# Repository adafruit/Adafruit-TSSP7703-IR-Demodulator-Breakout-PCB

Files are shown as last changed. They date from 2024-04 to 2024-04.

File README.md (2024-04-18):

## Adafruit TSSP77038 38KHz Infrared IR Demodulator Breakout - STEMMA JST PH 2mm PCB

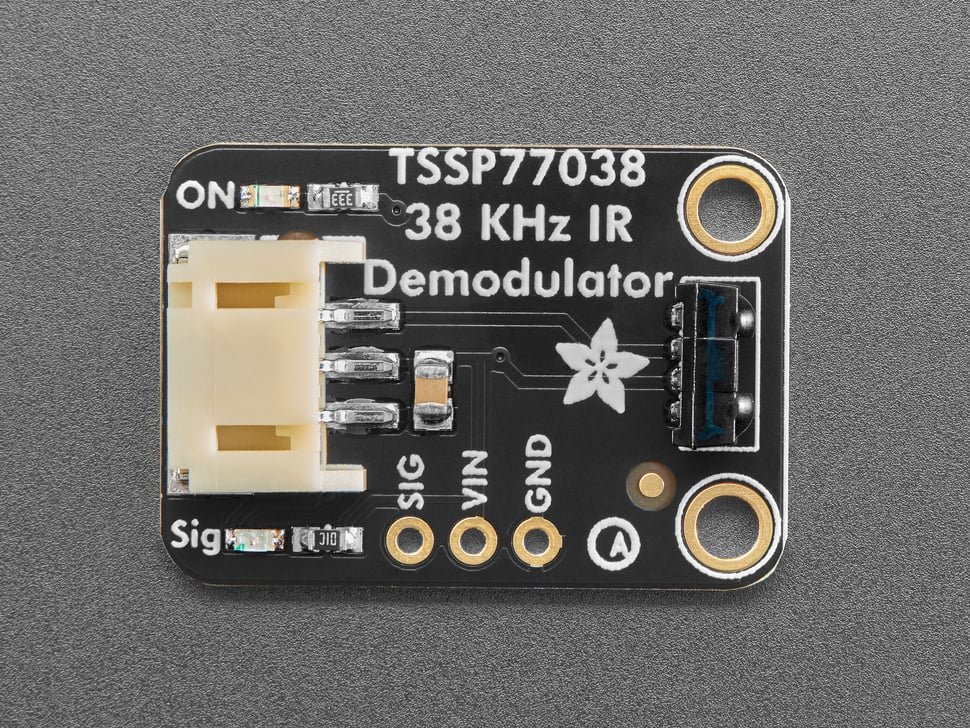
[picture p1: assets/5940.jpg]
<a href="http://www.adafruit.com/products/5940"><br/>
Click here to purchase one from the Adafruit shop</a>

PCB files for the Adafruit TSSP77038 38KHz Infrared IR Demodulator Breakout - STEMMA JST PH 2mm. 

Format is EagleCAD schematic and board layout
* https://www.adafruit.com/product/5940

### Description

While designing our IR decoding breakout we noticed the TSSP series of chips from Vishay, these are simpler than more 'remote control' receivers in that they don't do any filtering on the codes received: you really just get the demodulated-from-38KHz-signal output.

According to Vishay, they're designed for "Reflective Sensing, Light Barriers, and Fast Proximity Applications". These sensors could be interesting for use when you want a less-'intelligent' IR decoder, or for proximity projects where you don't want to go all-out for a VCNL I2C sensor. These are good for creating break-beams where the IR light is modulated rather than just solid on, because you won't be affected by other IR signals or ambient light changes.

This board will work nicely for a variety of IR detecting projects, and with mounting holes and a cable, a lot easier to mount in enclosures and on devices. Using a 2mm pitch STEMMA JST PH cable with headers or alligator clips on the end, you can easily wire this board without any soldering.

Note that this board is specifically for proximity sensing or break-beam projects, while it can receive 38KHz IR remote control signals - there isn't a filter system so you'll get a lot of spurious signals.

Each STEMMA board is a fully assembled and tested PCB but no cable. No soldering is required to use it, but you will need to pick up a 2mm pitch, 3-pin STEMMA JST PH cable. Alternatively, if you do want to solder, there's a 0.1" spaced header for power/ground/signal.

### License

Adafruit invests time and resources providing this open source design, please support Adafruit and open-source hardware by purchasing products from [Adafruit](https://www.adafruit.com)!

Designed by Limor Fried/Ladyada for Adafruit Industries.

Creative Commons Attribution/Share-Alike, all text above must be included in any redistribution. 
See license.txt for additional details.

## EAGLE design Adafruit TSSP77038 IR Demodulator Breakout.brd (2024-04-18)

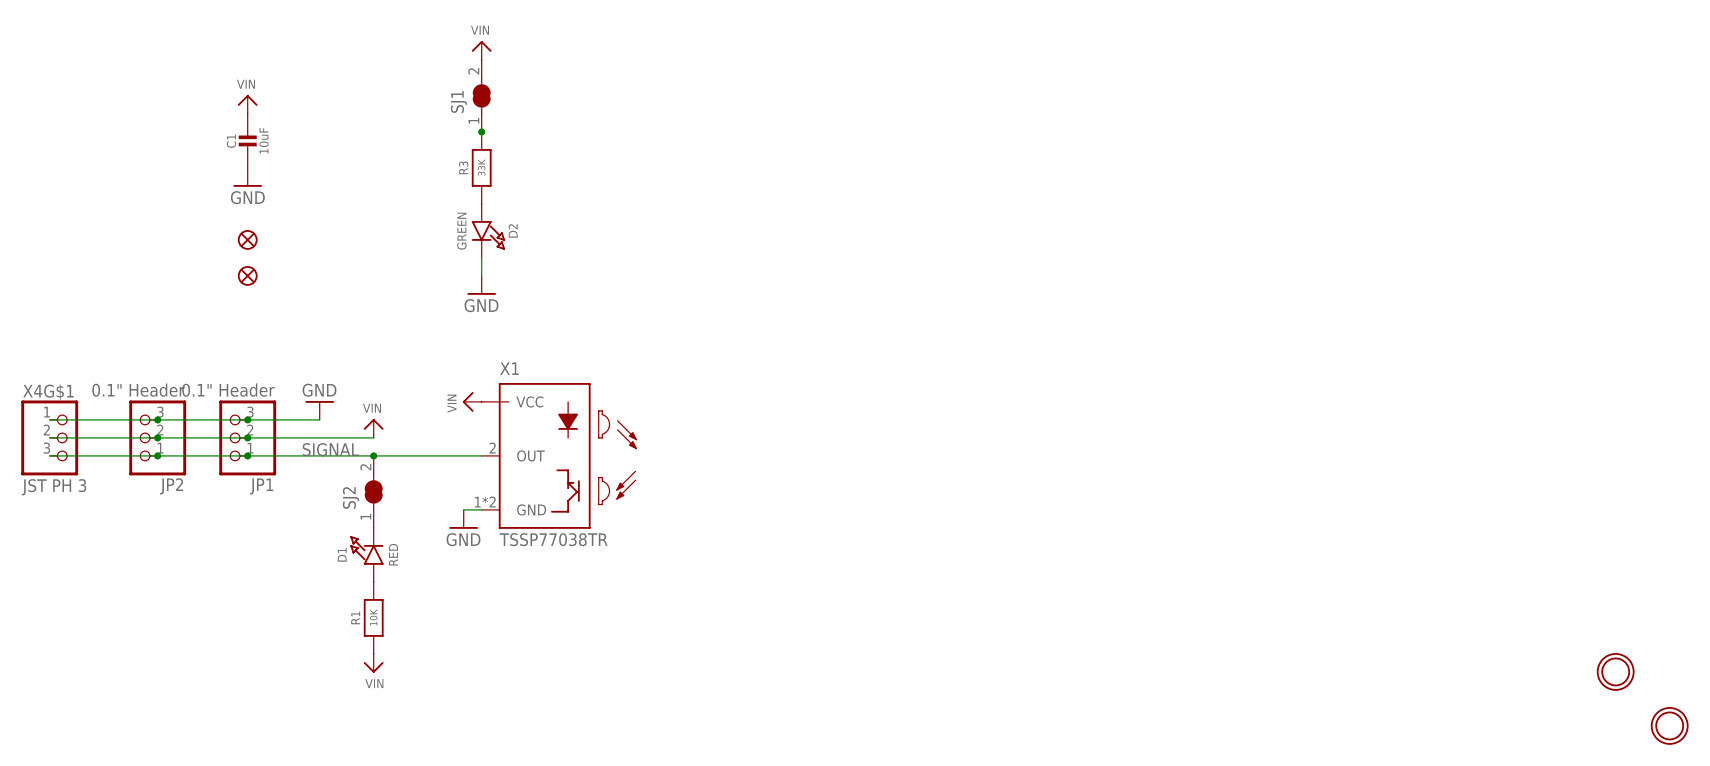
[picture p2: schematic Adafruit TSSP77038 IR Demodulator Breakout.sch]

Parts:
C1: 10uF; 0805-NO
D1: RED; CHIPLED_0603_NOOUTLINE
D2: GREEN; CHIPLED_0603_NOOUTLINE
FID2, FID3: FIDUCIAL_1MM
JP1: 0.1" Header; 1X03_OVAL
JP2: 0.1" Header; 1X03_ROUND_76
R1: 10K; 0603-NO
R3: 33K; 0603-NO
SJ1, SJ2: SOLDERJUMPER_CLOSED; SOLDERJUMPER_CLOSEDWIRE
U$1, U$8: MOUNTINGHOLE2.5; MOUNTINGHOLE_2.5_PLATED
X1: TSSP77038TR; VEML7700
X4: JST PH 3; JSTPH3

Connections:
GND: C1.2, D2.C, JP1.3, JP2.3, X1.1 (GND), X1.4 (GND), X4.1
unnamed: R3.2, SJ1.1
unnamed: D1.C, SJ2.1
unnamed: D1.A, R1.2
unnamed: D2.A, R3.1
SIGNAL: JP1.1, JP2.1, SJ2.2, X1.2 (OUT), X4.3
VIN: C1.1, JP1.2, JP2.2, R1.1, SJ1.2, X1.3 (VCC), X4.2

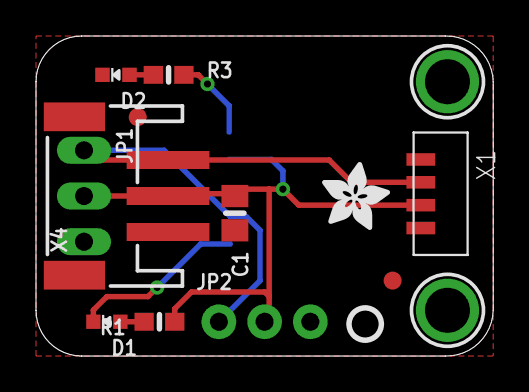
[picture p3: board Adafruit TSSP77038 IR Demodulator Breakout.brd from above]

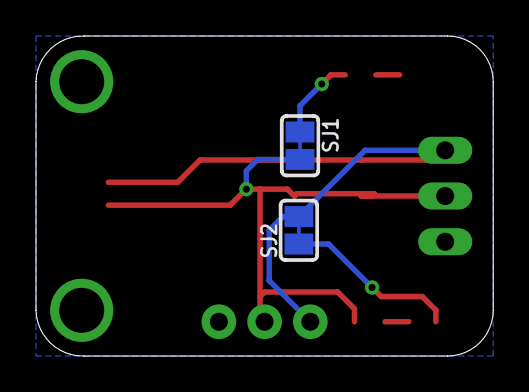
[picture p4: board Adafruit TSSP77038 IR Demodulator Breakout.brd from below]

Board: 2 copper layers, 25.4 x 17.8 mm, 33 parts (12 on the bottom side), 7 nets.

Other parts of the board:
PLABEL0: PLABEL0
PLABEL1: PLABEL1
PLABEL5: PLABEL5
PLABEL6: PLABEL6
PLABEL8: PLABEL8
PLABEL9: PLABEL9
PLABEL10: PLABEL10
PLABEL13: PLABEL13
PLABEL14: PLABEL14
PLABEL15: PLABEL15
PLABEL16: PLABEL16
PLABEL17: PLABEL17
PLABEL18: PLABEL18
PLABEL19: PLABEL19
PLABEL20: PLABEL20
PLABEL21: PLABEL21
U$5: PCBFEAT-REV-040
U$10: ADAFRUIT_3.5MM

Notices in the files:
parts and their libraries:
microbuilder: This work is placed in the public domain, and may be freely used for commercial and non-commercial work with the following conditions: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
